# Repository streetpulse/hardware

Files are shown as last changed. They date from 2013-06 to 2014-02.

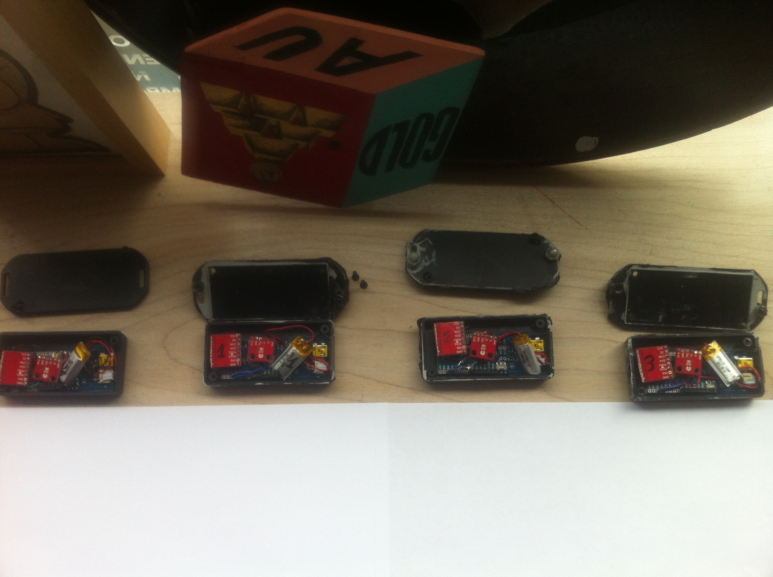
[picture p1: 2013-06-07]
bin sensor/images/sensors.JPG

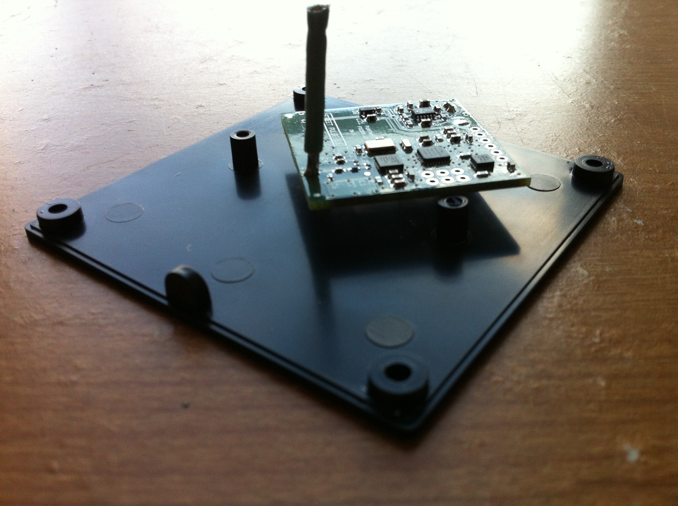
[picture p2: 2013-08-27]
bin sensor/images/sensors1.JPG

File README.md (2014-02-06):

hardware
========

All hardware for streetpulse are presented in this folder: that's sensors, wireless communication and receiver.
all contents on this repository are under Creative commons (Attribution-NonCommercial-ShareAlike 3.0 Unported)



Sensors
========

The Sensors are composed of an electronic board, a battery, a solar cell and an enclosure.

You will find the PCB file (Eagle software) to make the electronic board for sensors from scratch, with the list of components used. Most manufacturers will take these files and can produce the sensor modules without additional work.

- garbageSensor.brd 
- garbageSensor.sch
- bom-street-pulse.xls
 
For the enclosure containing the modules, We used a **BUD CU-791-MB** but other boxes might do.

Regarding the solar cell, we imported a model from China, the **SZGD6060-4P**, but all models capable of 2Volts at 200mA max (max Power 0.4 Watt) would do.

Base
====
The "base" that receives data is a **Raspberry Pi** with an antenna and a wireless transceiver from [Sparkfun][https://www.sparkfun.com/products/705], see pictures in the base folder. Note that we first tried to use
an arduino wireless Shield for this (that's the picture) but  performance was too poor.

Aside from better performance, we also recommend the use of Raspberry Pi as it saves data locally before sending it to a server. 
This allowed us to cope with unreliable wifi connection and network loss of data. It also serves as additional backup.

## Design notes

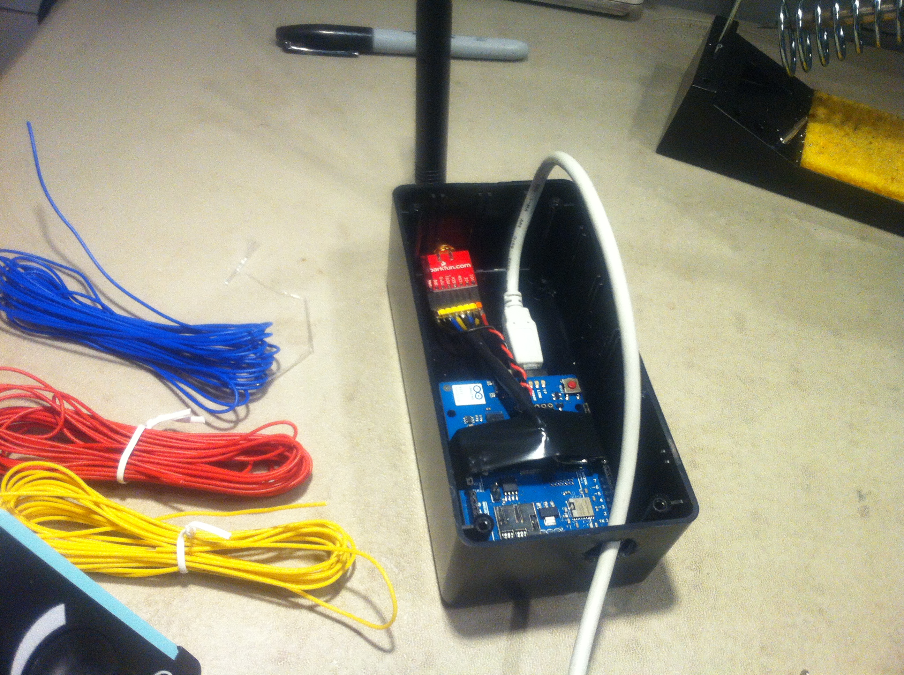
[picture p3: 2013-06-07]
base/base_in_box_arduino.JPG

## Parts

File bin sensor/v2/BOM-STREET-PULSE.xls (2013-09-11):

Fourth Art Block inc.
BOM: SPRC2 BOARD Rev 1.2
Date: 07/24/2013
Item | SPE part # | Qty/ bd | Reference desig. | Customer part # | Value | Footprint | Description / Extended specs | Mnfr or vendor description/ specs | Manfr. | Manf part # | Distributor | Distributor P/N
1 |  | 2 | C1, C2 |  | 22pF | 0603 | CAP CER 22PF 50V 2% NP0 0603 | CAP CER 22PF 50V 2% NP0 0603 | Kemet | C0603C220G5GACTU | Digikey | 399-7873-6-ND
2 |  | 1 | C3 |  | 33nF | 0603 | CAP CER 33000PF 10% 25V X7R 0603 | CAP CER 33000PF 10% 25V X7R 0603 | Rohm Semiconductor | MCH182CN333KK | digikey | 511-1176-1-ND
3 |  | 1 | C4 |  | 2.2nF | 0402 | CAP CER 2200PF 50V 10% X7R 0402 | CAP CER 2200PF 50V 10% X7R 0402 | taiyo Yuden | UMK105B7222KV-F | digikey | 587-1221-6-ND
4 |  | 1 | C5 |  | 4.7pF | 0402 | CAP CER 4.7PF 100V NP0 0402 +- 0.1pF | CAP CER 4.7PF 100V NP0 0402 | kemet | CBR04C479B1GAC | digikey | 399-8585-6-ND
5 |  | 1 | C6 |  | 1.0pF | 0402 | CAP CER 1PF 100V NP0 0402 +-0.1pf | CAP CER 1PF 100V NP0 0402 | kemet | CBR04C109B1GAC | digikey | 399-8599-6-ND
6 |  | 1 | C7 |  | 1.5pF | 0402 | CAP CER 1.5PF 100V NP0 0402 +-0.1pF | CAP CER 1.5PF 100V NP0 0402 | kemet | CBR04C159B1GAC | digikey | 399-8597-6-ND
7 |  | 1 | L1 |  | 3.9nH | 0402 | INDUCTOR 3.9NH 0402 SMD +-5% | INDUCTOR 3.9NH 0402 SMD | Bourns inc. | CW100505-3N9J | digikey | CW100505-3N9JDKR-ND
8 |  | 1 | L2 |  | 2.7nH | 0402 | INDUCTOR 2.7NH 5% 0402 +- 5% | INDUCTOR 2.7NH 5% 0402 | TE connectivity | 1-1624112-7 | digikey | A103706DKR-ND
9 |  | 1 | L3 |  | 8.2nH | 0402 | INDUCTOR 8.2NH 0402 SMD +-5% | INDUCTOR 8.2NH 0402 SMD | Bourns inc. | CW100505-8N2J | digikey | CW100505-8N2JCT-ND
10 |  | 1 | C8 |  | 10nF | 0603 | CAP CER 10000PF 50V 10% X7R 0603 | CAP CER 10000PF 50V 10% X7R 0603 | SAMSUNG | CL10B103KB8NNNC | Digikey | 1276-1009-1-ND
11 |  | 1 | C9 |  | 1nF | 0603 | CAP CER 1000PF 200V 10% X7R 0603 | CAP CER 1000PF 200V 10% X7R 0603 | Kemet | C0603C102K2RACTU | Digikey | 399-7832-1-ND
12 |  | 2 | C11, C12 |  | 100nF | 0603 | CAP CER 0.1UF 50V 10% X7R 0603 | CAP CER 0.1UF 50V 10% X7R 0603 | Kemet | C0603C104K5RACTU | Digikey | 399-5089-6-ND
13 |  | 4 | C14, C15, C23, C100 |  | 0.1uF | 0603 | CAP CER 0.1UF 50V 20% Y5V 0603 | CAP CER 0.1UF 50V 20% Y5V 0603 | YAGEO | CC0603MRY5V9BB104 | Digikey | 311-1366-6-ND
14 |  | 3 | C10, C16, C19 |  | 10uF | 0603 | CAP CER 10UF 6.3V 10% X5R 0603 | CAP CER 10UF 6.3V 10% X5R 0603 | SAMSUNG | CL10A106KQ8NNWC | Digikey | 1276-1868-6-ND
15 |  | 2 | C17,C21,C20 |  | 1uF | 0603 | CAP CER 1UF 10V 10% X5R 0603 | CAP CER 1UF 10V 10% X5R 0603 | Kemet | C0603C105K8PACTU | digikey | 399-3118-6-ND
16 |  | 1 | C18, C13 |  | 4.7uF | 0603 | CAP CER 4.7UF 6.3V 10% X5R 0603 | CAP CER 4.7UF 6.3V 10% X5R 0603 | Kemet | C0603C475K9PACTU | digikey | 399-3482-6-ND
17 |  | 1 | L4 |  | 10uH | 0806 | INDUCTOR 10UH 150MA 10% SMD | INDUCTOR 10UH 150MA 10% SMD | Taiyo Yuden | LBR2012T100K | Digikey | 587-2045-6-ND
18 |  | 1 | Q1 |  | CRYSTAL 16MHZ 12PF | 4-SMD | CRYSTAL 16.000MHZ 12PF SMD | CRYSTAL 16.000MHZ 12PF SMD | TXC corporation | AB-16.000MAGE-T | Digikey | 887-1707-6-ND
19 |  | 1 | R2 |  | 22KOhm | 0603 | RES 22.0K OHM 1/8W 1% SMD 0603 | RES 22.0K OHM 1/8W 1% SMD 0603 | Vishay | MCT06030C2202FP500 | Digikey | MCT0603-22.0K-CFDKR-ND
20 |  | 3 | R3, R4, R8 |  | 10KOhm | 0603 | RES 10.0K OHM 1/8W 1% SMD 0603 | RES 10.0K OHM 1/8W 1% SMD 0603 | Vishay | MCT06030C1002FP500 | Digikey | MCT0603-10.0K-CFDKR-ND
21 |  | 1 | R5 |  | 1024KOhm | 0603 | RES 1.02M OHM 1/10W 1% 0603 SMD | RES 1.02M OHM 1/10W 1% 0603 SMD | Vishay | CRCW06031M02FKEA | Digikey | 541-1.02MHDKR-ND
22 |  | 1 | R6 |  | 332KOhm | 0603 | RES 332K OHM 1/16W .5% 0603 SMD | RES 332K OHM 1/16W .5% 0603 SMD | Susumu | RR0816P-3323-D-51D | Digikey | RR08P332KDDKR-ND
23 |  | 1 | R7 |  | 40.2KOhm | 0603 | RES 40.2K OHM 1/8W 1% 0603 | RES 40.2K OHM 1/8W 1% 0603 | Stackpole Electronics Inc | RNCP0603FTD40K2 | Digikey | RNCP0603FTD40K2DKR-ND
24 |  | 1 | U1 |  | NRF24L01P QFN20 | QFN 20 | NRF24L01P SMD QFN20 | RF Transceiver SNGL-CHP ULTR-LW POW 2.4GHz TRNSCVR | Nordic semiconductor | nRF24L01P-R | MOUSER | 949-NRF24L01P-R
25 |  | 1 | U2 |  | ATMEGA168 MLF 32 | MLF 32 | ATMEGA168 MLF 32 | IC MCU 8BIT 32KB FLASH 32QFN | Atmel | ATMEGA328P-MUR | Digikey | ATMEGA328P-MURDKR-ND
26 |  | 1 | U3 |  | MMA8452QT QFN-16 | QFN 16 | ACCELEROMETER 3AXIS 16QFN | IC ACCELEROMETER 3AXIS 16QFN | Freescale Semiconductor | MMA8452QT | Digikey | MMA8452QT-ND
27 |  | 1 | U4 |  | LTC3105 MSOP-12 | MSOP 12 | LTC3105 MSOP-12 | IC CONV DC/DC STEP DOWN 12-MSOP | Linear Technology | LTC3105EMS#PBF | Digikey | LTC3105EMS#PBF-ND
28 |  | 1 | U6 |  | TPS78233DDCT | TSOT-23-5 | IC REG LDO 3.3V 0.15A 5SOT | IC REG LDO 3.3V 0.15A 5SOT | Texas Instruments | TPS78233DDCT | Digikey | 296-24120-1-ND
29 |  | 1 | Y2 |  | RESONATORSMD | 3-SMD, Non-Standard | CER RESONATOR 8.00MHZ SMD | CER RESONATOR 8.00MHZ SMD | Murata | CSTCE8M00G55-R0 | Digikey | 490-1195-6-ND

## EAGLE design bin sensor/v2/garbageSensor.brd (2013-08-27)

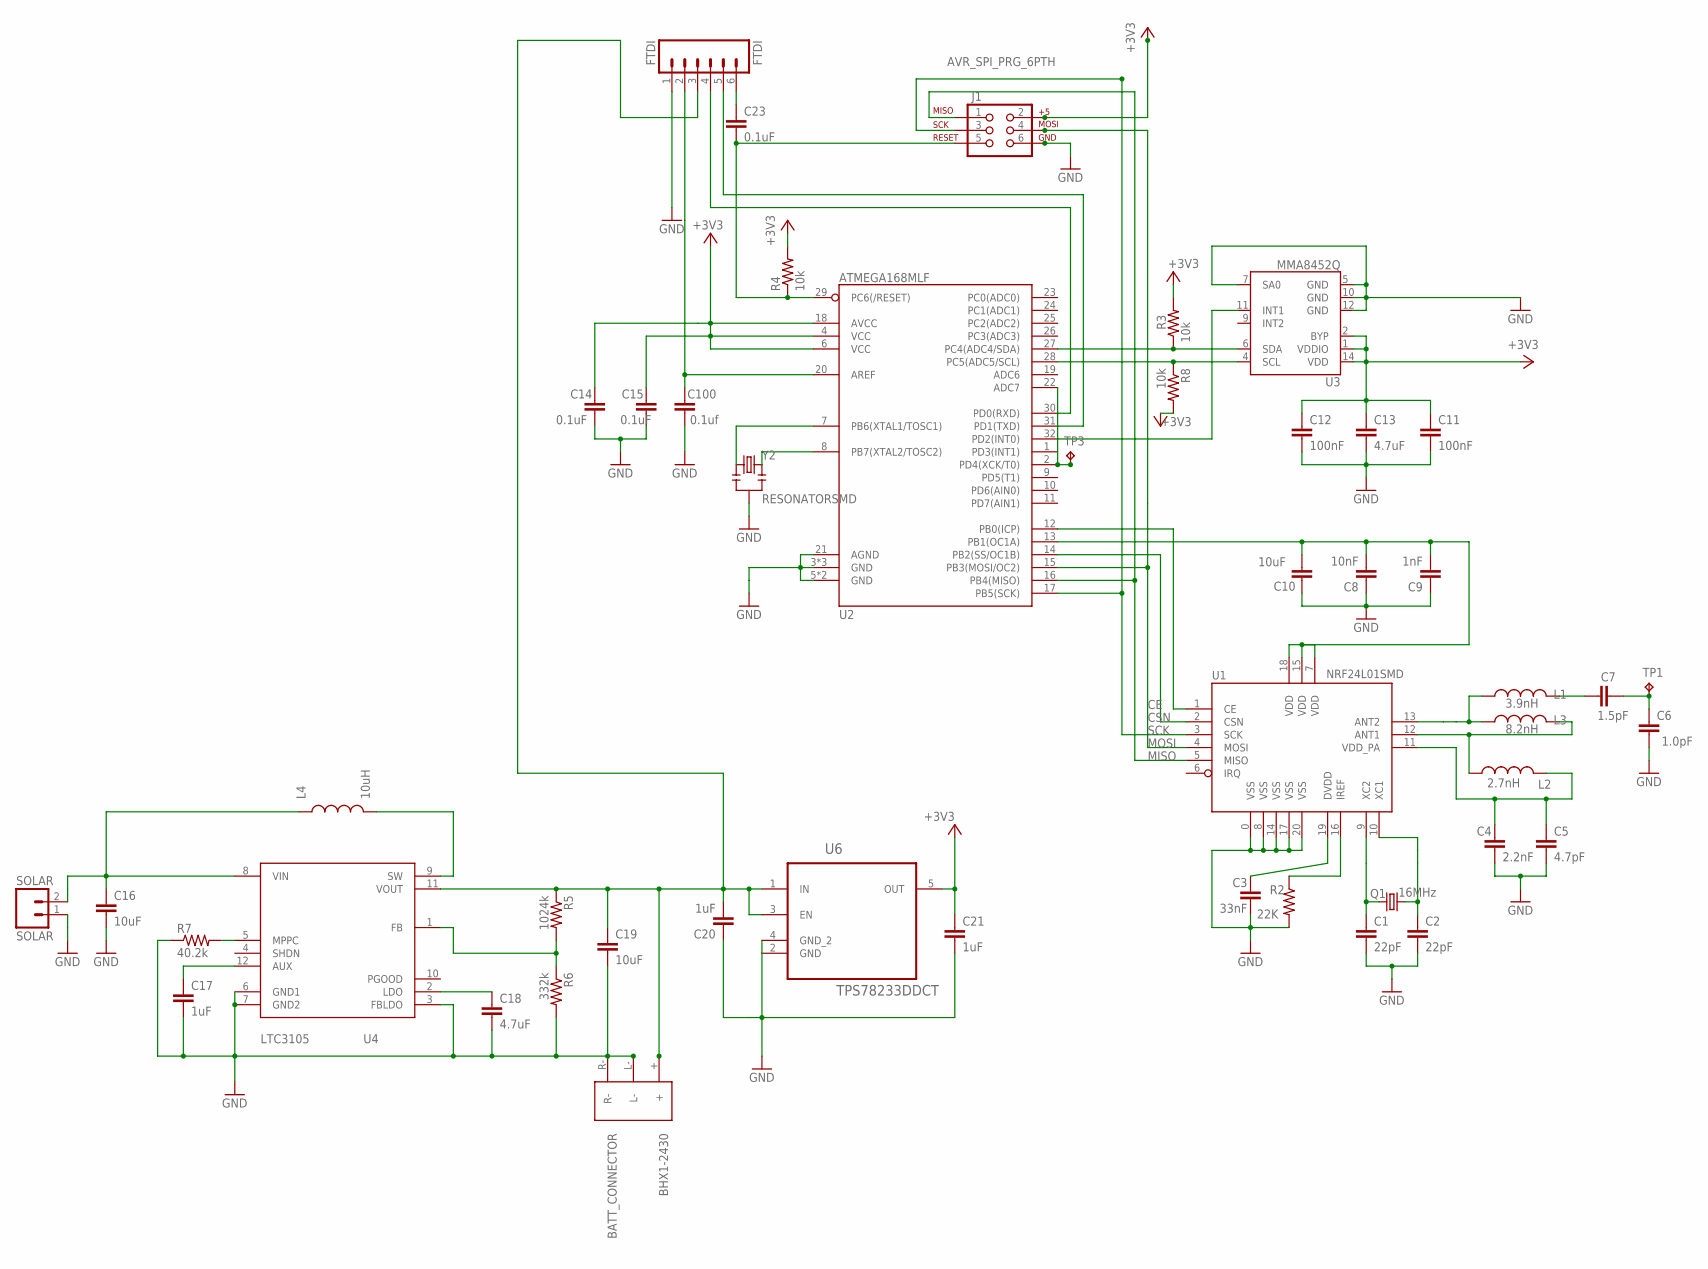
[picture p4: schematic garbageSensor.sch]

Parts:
B1: BATT_CONNECTOR; BHX1-2325
C1, C2: 22pF; 0603
C3: 33nF; 0603
C4: 2.2nF; C0402
C5: 4.7pF; C0402
C6: 1.0pF; C0402
C7: 1.5pF; C0402
C8: 10nF; 0603
C9: 1nF; 0603
C10, C16, C19: 10uF; C0603K
C11, C12: 100nF; C0603K
C13, C18: 4.7uF; C0603K
C14, C15: 0.1uF; C0603K
C17, C20, C21: 1uF; C0603K
C23: 0.1uF; 0603-CAP
C100: 0.1uf; 0603-CAP
FTDI: FTDI; 1X06
J1: AVR_SPI_PRG_6PTH; 2X3
L1: 3.9nH; C0402
L2: 2.7nH; C0402
L3: 8.2nH; C0402
L4: 10uH; 0806
Q1: 16MHz; CRYSTAL-SMD-5X3
R2: 22K; 0603
R3, R4, R8: 10k; R0603
R5: 1024k; R0603
R6: 332k; R0603
R7: 40.2k; R0603
SOLAR: SOLAR; 1X02_LOCK
TP1: TPB2,54; B2,54
TP3: TPTP06R; TP06R
U1: NRF24L01SMD; QFN20
U2: ATMEGA168MLF; MLF32
U3: MMA8452Q; QFN-16_0.5MM
U4: CHARGER; MSOP-12
U6: TPS78233DDCT; SOT95P280X110-5N
Y2: RESONATORSMD; RESONATOR-SMD

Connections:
+3V3: C11.1, C12.1, C13.1, C14.2, C15.2, C21.1, J1.2, R3.2, R4.2, R8.2, U2.4 (VCC), U2.6 (VCC), U2.18 (AVCC), U3.1 (VDDIO), U3.2 (BYP), U3.14 (VDD), U6.5 (OUT)
ACCELERO_INTERRUPT: U2.32 (PD2(INT0)), U3.11 (INT1)
ANT: C6.2, C7.2, TP1.TP
ANTENNA1: L1.1, L3.1, U1.13 (ANT2)
ANTENNA2: L2.1, L3.2, U1.12 (ANT1)
ANTENNA3: C4.1, C5.1, L2.2, U1.11 (VDD_PA)
AREF: C100.1, FTDI.2, U2.20 (AREF)
AUX: C17.1, U4.12 (AUX)
CE: U1.1 (CE), U2.12 (PB0(ICP))
CSN: U1.2 (CSN), U2.14 (PB2(SS/OC1B))
FB: R5.2, R6.1, U4.1 (FB)
GND: B1.L-, B1.R-, C1.2, C2.2, C3.2, C4.2, C5.2, C6.1, C8.1, C9.1, C10.2, C11.2, C12.2, C13.2, C14.1, C15.1, C16.2, C17.2, C18.2, C19.2, C20.1, C21.2, C100.2, FTDI.1, J1.6, R2.2, R6.2, R7.1, SOLAR.1, U1.0 (VSS), U1.8 (VSS), U1.14 (VSS), U1.17 (VSS), U1.20 (VSS), U2.3 (GND), U2.5 (GND), U2.21 (AGND), U2.GND1 (GND), U2.GND2 (GND), U2.GND3 (GND), U3.5 (GND), U3.7 (SA0), U3.10 (GND), U3.12 (GND), U4.3 (FBLDO), U4.6 (GND1), U4.7 (GND2), U6.2 (GND), U6.4 (GND_2), Y2.2
LDO: C18.1, U4.2 (LDO)
MISO: J1.1, U1.5 (MISO), U2.16 (PB4(MISO))
MOSI: J1.4, U1.4 (MOSI), U2.15 (PB3(MOSI/OC2))
MPPC: R7.2, U4.5 (MPPC)
unnamed: C1.1, Q1.1, U1.9 (XC2)
unnamed: C2.1, Q1.3 (2), U1.10 (XC1)
unnamed: R2.1, U1.16 (IREF)
unnamed: C3.1, U1.19 (DVDD)
unnamed: TP3.TP, U2.2 (PD4(XCK/T0))
unnamed: C7.1, L1.2
unnamed: L4.P$2 (2), U4.9 (SW)
unnamed: C23.1, FTDI.6
RESET: C23.2, J1.5, R4.1, U2.29 (PC6(/RESET))
RX: FTDI.4, U2.30 (PD0(RXD))
SCK: J1.3, U1.3 (SCK), U2.17 (PB5(SCK))
SCL: R8.1, U2.28 (PC5(ADC5/SCL)), U3.4 (SCL)
SDA: R3.1, U2.27 (PC4(ADC4/SDA)), U3.6 (SDA)
SOLAR: C16.1, L4.P$1 (1), SOLAR.2, U4.8 (VIN)
TX: FTDI.5, U2.31 (PD1(TXD))
VBATT: B1.+, C19.1, C20.2, FTDI.3, R5.1, U4.11 (VOUT), U6.1 (IN), U6.3 (EN)
WIRELESS_POWER_LINE: C8.2, C9.2, C10.1, U1.7 (VDD), U1.15 (VDD), U1.18 (VDD), U2.13 (PB1(OC1A))
XTAL1: U2.7 (PB6(XTAL1/TOSC1)), Y2.1
XTAL2: U2.8 (PB7(XTAL2/TOSC2)), Y2.3

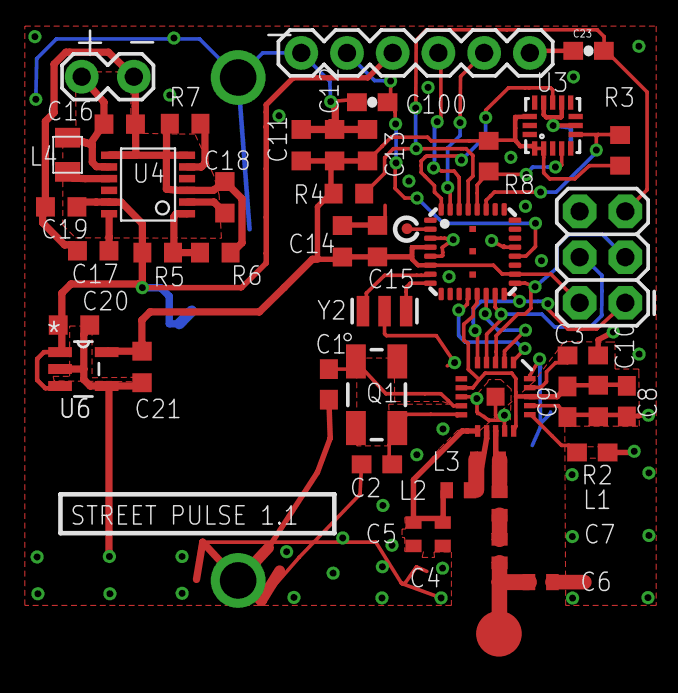
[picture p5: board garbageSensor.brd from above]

Board: 2 copper layers, 47 parts (1 on the bottom side), 35 nets.

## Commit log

2013-06-07 board layout
    [garbageSensor.brd, garbageSensor.sch]
2013-06-07 added base info + images
    [garbageSensor.brd, garbageSensor.sch]
2013-08-27 updated newest hardware design
    - re-made repository structure for versions
    - added new image from latest hardware
    - added newest design files for hardware design
    [garbageSensor.brd, garbageSensor.sch]
2013-09-11 added markdown elements
    [BOM-STREET-PULSE.xls]

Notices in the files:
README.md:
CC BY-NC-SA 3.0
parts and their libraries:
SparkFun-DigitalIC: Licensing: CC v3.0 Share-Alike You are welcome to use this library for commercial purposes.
